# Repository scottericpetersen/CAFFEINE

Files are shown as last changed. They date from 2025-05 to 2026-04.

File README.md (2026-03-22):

# CAFFEINE
**Collaborative Affordable Framework For Experiments In Networked Electronics**

<p align="center">
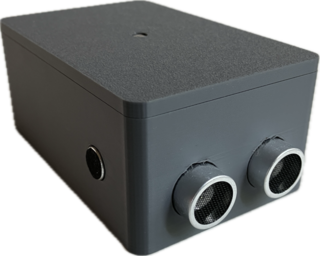
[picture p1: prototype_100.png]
  
</p>

This repository contains files pertaining to the CAFFEINE project, an ongoing research project undertaken by the Open Music Initiative at Yale University. 

## Description

CAFFEINE is a mixed hardware/software framework that enables real-time low-latency sonification of sensor data from wearable embedded systems. The framework utilizes a many-to-many network topology, allowing unlimited pods and clients, constrained only by hardware availability. Wireless, battery-powered pods, built around the ESP32 microcontroller platform, host sensor arrays that capture diverse data, including motion, sound, distance, and light. Data are transmitted to a broker program that routes them to registered clients for sonification or further processing. CAFFEINE prioritizes accessibility and affordability, designed for artists and musicians with minimal technical expertise. Its extensible architecture supports creative applications, from live movement sonification to environmental data-driven compositions, reducing barriers to networked sensor technologies.

## File Directory

Below is a brief description of files found in the CAFFEINE repository

- **client_files**: these are example files showing how to receive and use data from the pods. Currently, there are SuperCollider and Max/MSP examples.
- **osc_programs**: this folder contains the OSC version of the pod and broker programs.
- **paper**: contains the CAFFEINE ICMC 2025 paper and test result files
- **depricated**: contains depricated versions of the CAFFEINE software. We do not recommend using the versions in this file.
- **utilities**: this folder contains the test suite of programs used to procure analysis data of data transmission rates for the CAFFEINE paper.
- **CAD**: contains CAD files for the enclosure

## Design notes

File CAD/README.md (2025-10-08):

## CAFFEINE POD CAD Model

This folder contains OpenSCAD sources for the CAFFEINE enclosure.

Files:
- `box3.scad`: Parametric model for the base and cover
- `box3.stl`: Example export

Prerequisites:
- Install OpenSCAD (`https://openscad.org`)

How to render and export STL:
1. Open `box3.scad` in OpenSCAD.
2. Optional: Adjust parameters at the top of the file (units are millimeters):
   - `box_length`, `box_width`, `box_height`, `wall_thickness`
   - Corner radii: `outer_radius`, `inner_radius`
   - Cover/lip: `cover_thickness`, `lip_height`, `lip_clearance`
   - Holes/vents: `sensor_hole_*`, `sensor_protrusion_*`, `left_hole_*`, `sensor_strip_*`
   - Surface quality: `$fn` (higher = smoother, slower render)
3. Render:
   - Preview: press F5
   - Final (CGAL) render: press F6 (required before exporting STL)
4. Export STL:
   - File → Export → Export as STL
5. For CEID Bambu Printers, no printer settings need to be modified, fill sparcity could be increased for slighly faster print time.

Notes:
- Measurements are in millimeters.
- `lip_clearance` and hole diameters include small tolerances adjusted through trial and error

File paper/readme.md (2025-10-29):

This folder contains the CAFFEINE paper submitted to and included in the procedings of ICMC 2025. The logs folder contains all results of the tests performed for inclusion in the paper. The test code to perform those tests can be found in CAFFEINE/utilities/Test Suite.

ERRATA: 

In the wiring diagram (Fig. 1) the MPU6050 is connected as such: SDA --> pin 5, SCL --> pin 4. However, the current version of the caffeine_osc.ino file as these pins reversed. So either, in the actual circuit, connect SDA to pin 4, and SCL to pin 5. Or, you *should be able to* leave the wiring as in the paper and, in the caffeinepod_osc.ino (and udp version) change the line

```
  Wire.setPins(4, 5);
```

to

```
  Wire.setPins(5, 4);
```

AMBIGUITIES:

The paper does not clarify the nature of the photo-resistor (ldr) and the resistor (R1) connected to it (and GND.) Because photo resistors come in varying resistance values, you should choose the same value for the resistor (R1) as for LDR. This is because the two form a voltage divider where Vout = Vcc(R1/R1+LDR). So at average light, the output values for this system (12-bit ADC) sit around ~2048. As light decreases, resistance of LDR increases and the value goes down to 0. Similarly, as light increases, the value will go up (from ~2048) to a maximum of 4095. You can bias this one way or another by varying the R1 and LDR resistance values. However, it is advisable to do this in software rather than in hardware as you may change the functional range of the light sensor by changing the relationship of R1 and LDR, reducing the range where effective results can be achieved resulting in mostly high (4095) or mostly 0 values when the ambient light level changes.

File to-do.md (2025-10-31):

# Timeline of Improvements to CAFFEINE Framework

Current to-do

- Enclosure battery notches (last on enclosure wishlist)

1. Broker

  - Allow clients to specify multiple pods simultaneously
  - Allow clients to specify which data to receive (ex. only x,y)
  - Allow clients to unregister (stop receiving data)
  - Allow clients to request list of available pods

2. Client
  - graphic visualization of incoming data

3. Pod
  - Software algorithms

DONE: 

- Schedule meeting with CAD/Print team
- Initial Print
- Print V2

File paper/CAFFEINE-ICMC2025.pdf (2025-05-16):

## CAFFEINE: Collaborative Affordable Framework For Experiments in Interactive Networked Electronics

Scott Eric Petersen
Yale University
scott.petersen@yale.edu

Alejandro Mayagoitia
Yale University
alejandro.mayagoitia@yale.edu

ABSTRACT

CAFFEINE is a mixed hardware/software framework that enables real-time low-latency sonification of sensor data from wearable embedded systems. The framework utilizes a many-to-one-to-many network topology, allowing unlimited pods and clients, constrained only by hardware availability. Wireless, battery-powered pods, built around the ESP32 microcontroller platform, host sensor arrays that capture diverse data, including motion, sound, distance, and light. Data are transmitted to a broker program that routes them to registered clients for sonification or further processing. CAFFEINE prioritizes accessibility and affordability, designed for artists and musicians with minimal technical expertise. Its extensible architecture supports creative applications, from live movement sonification to environmental data-driven compositions, reducing barriers to networked sensor technologies. The framework files and utilities can be found on the GitHub project [1].

### 1. INTRODUCTION

Numerous commercial motion capture systems have been developed specifically for use in musical contexts. They have various form factors, but most are designed to be worn[2] or attached to an instrument[3]. Some companies offer a variety of devices[4], but the functionality of each device is fixed and the systems are only extendable in software. In contrast, the CAFFEINE framework integrates open-source software with low-cost, commercially available hardware to provide flexible, extensible configurations that support a wide range of applications.

### 2. DESCRIPTION

CAFFEINE enables real-time, low-latency sonification of sensor input from small, wearable embedded systems called “pods” in a network topology of many-to-one-to-many. Any number of collaborators can register to receive data from any number of pods on the network. The possible number of pods and clients is limited only by hardware. The framework is affordable, reproducible, and accessible for those with little to no hardware and software development knowledge, and the use of the system is simple once it is set

Copyright: ©2025 Scott Eric Petersen et al. This is an open-access article distributed under the terms of the Creative Commons Attribution License 3.0 Unported, (http://creativecommons.org/licenses/by/3.0/) which permits unrestricted use, distribution, and reproduction in any medium, provided the original author and source are credited.

up. Collaborators simply need to power on the pods, start the data broker program, and register their computers with the broker to begin receiving sensor data. The simplicity of the system allows musicians to focus on composition and performance, rather than technology.
We anticipate diverse applications of this system. An obvious use case would be the real-time sonification of movement where a pod is being worn by a dancer. However, a pod or pods could be used to train a machine learning model on complex human gestures. Or, in a conceptual space, we imagine long-scale musical forms could be informed by light and temperature tracked over days or weeks by a pod that is installed and stationary, or being transported through a space by an autonomous vehicle or kinetic sculpture. Whatever the application, the CAFFEINE framework has been designed to lower the barrier to electronic sensors and networked music.

### 3. HARDWARE

### 3.1 Overview

The minimal hardware configuration for CAFFEINE is an embedded system we refer to as a ‘pod’, and a laptop to program the pod and run both the broker program and a client program to sonify the data. An accessible network is also required as communication from the pod to the broker machine is done via Wi-Fi.

### 3.2 Pod

The CAFFEINE pod builds on and advances the embedded system introduced in our previous project, the [project anonymized] [5][6]. It consists of a circuit that connects multiple sensors to an Espressif ESP32 S3 development module [7]. The ESP32 is an ubiquitous microcontroller for embedded applications. Here, we specifically make use of one of its ADC channels and one of its I2C interfaces for sensor input, and its Wi-Fi capabilities for data transmission.

### 3.3 Power

The power for the ESP32 and the sensor array is supplied by a 3.7v 500 mAh lithium ion flat-pack battery [8] and a boost module to step up the voltage from 3.7v to 5v [9]. The boost module has the added benefit of allowing the battery to be charged in situ. The battery run time for this power configuration is approximately 150 minutes. A battery with a larger capacity can easily be substituted for longer performances.

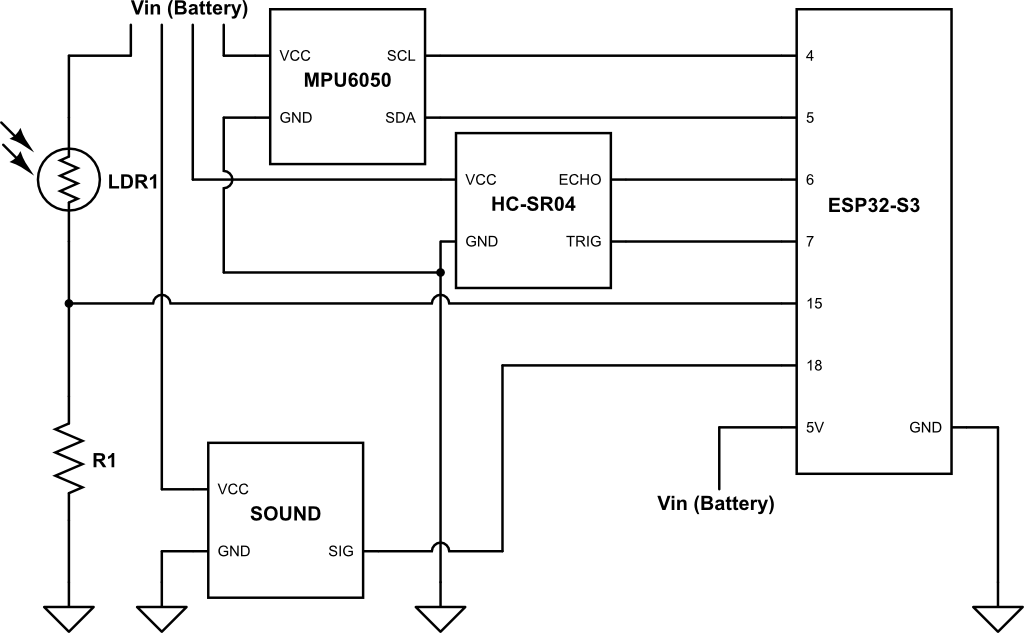
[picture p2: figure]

Figure 1: Circuit diagram for one pod.

### 3.4 Sensor Array

The sensor array consists of an HC-SR04 ultrasonic distance sensor [10], an MPU-6050 accelerometer/gyroscope [11], a Seeed Studio Grove Sound Sensor [12], and a photoresistor. The HC-SR04 distance sensor has an operational range of 2cm to 4m. However, in our tests, the device is unreliable at its extremes and is most stable between 11 cm and distances under 3.5 m. Additionally, noise occurs when the sensor is suddenly moved from the short end of its range to its maximum distance. The proper use of a low-pass filter to avoid noise is important if distances are used as triggers for musical events.
The MPU-6050 has a 3-axis accelerometer, a 3-axis gyroscope sensor, and a temperature sensor. The device is often used in drone construction and anywhere the orientation of a moving object is important [13]. Here, we provide only for the sending of the X, Y, and Z rotational velocity of the pod; however, sending other values is as simple as querying them. There are many libraries available for the MPU-6050 that simplify the acquisition and processing of its various sensor data. For our framework, we chose a library that was as lightweight and specific to the sensor as possible [14].
The sound sensor and the photoresistor are simple devices that return values based on momentary loudness and ambient light levels.

### 3.5 Cost

All pod components are commercially available. The total cost of the components required to build one pod, including a prototyping breadboard and cables, is approximately $50. To be cost-effective, many of the components we use are sold in packs of three to five. Thus, the cost of constructing subsequent pods decreases significantly. To illustrate, the market cost to obtain all the necessary parts for five pods from reputable online retailers is approximately $158 at the time of writing.

### 4. NETWORK TOPOLOGY

The network topology of many-to-many via a data broker means that only one IP address needs to be known for the system to function; the IP address of the computer that runs the broker program. All pods must be individually named and programmed with the IP address of the broker, and all clients must use that address to register for data. Institutional and home networks are compatible with CAF-FEINE; however, we recommend using a dedicated, private router that is offline and configured with a static IP address for the computer running the broker program. This setup eliminates the need to reprogram the pods when changing locations and only requires the broker’s IP address to be published once, simplifying client registration regardless of where the system is deployed.

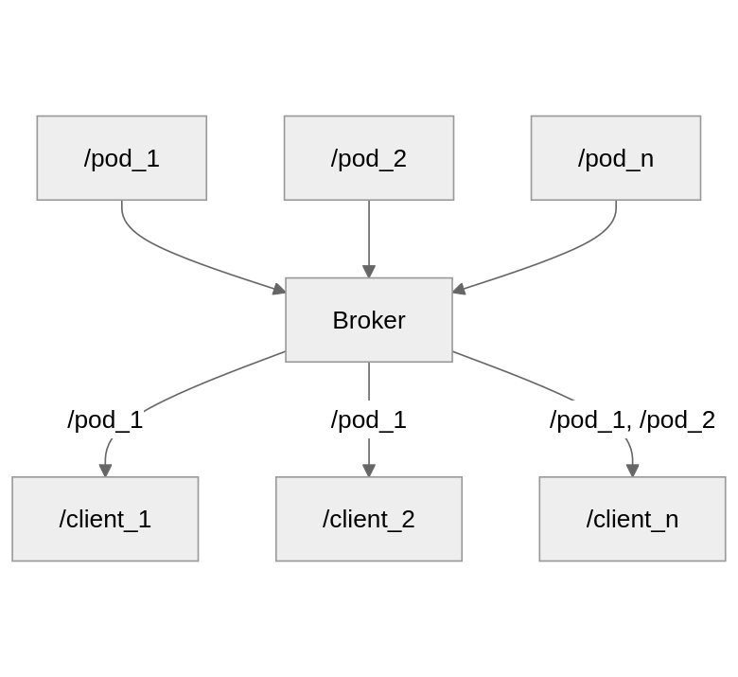
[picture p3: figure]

Figure 2: A CAFFEINE configuration where n number of pods are connected in an arbitrary way to n number of clients via the broker.

### 5. SOFTWARE

### 5.1 Overview

The software configuration for CAFFEINE consists of two files, an Arduino file that runs on the pod that defines its behavior, and a Python file that runs on the computer acting as the data broker that receives messages from the pod and forwards them to any registered clients on the localhost or the network. The last piece of a complete system is the client software to sonify the data received from the broker. Although that software must be written by the user of the system according to their specific needs, we provide SuperCollider examples that demonstrate functionality and best practices.

### 5.2 Embedded System Program

The pod program defines the name of the pod that identifies it to the broker. It registers the target computer running the broker software, attaches the pod to a specified network, measures the values from the attached sensor array, and sends those data to the broker program at a userspecified interval via one of two methods, either as a string via UDP or as typed data via OSC. Messages sent as strings via UDP are sent with the name of the pod followed by space-delimited sensor data as a string. Packets sent as OSC messages prepend the pod name as a symbol /pod1 and then an array of data where each comma denotes a potentially different data type. An example message sent via OSC might be

/ pod1 : [ 0 . 0 3 0 , 0 . 0 1 0 , −0.863 , 2253 ,
2 2 . 0 9 , 97]

where the first three data points are the X, Y, and Z values of the MPU-6050, the fourth data point is the loudness, the fifth is the distance registered by the HC-SR04 in centimeters, and the last is the light value registered by the photoresistor.

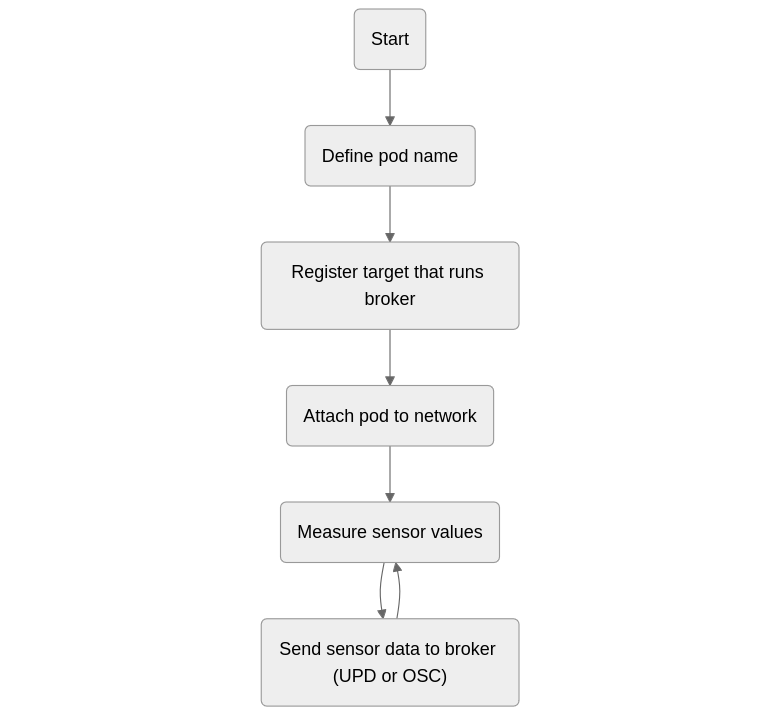
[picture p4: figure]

Figure 3: Embedded System Program flow control.

UDP and OSC communication have pros and cons. For UDP, string concatenation is done via a fixed-size character array. Thus, the memory allocation is secure and consistent, and messages are sent and received regularly, with jitter and packet loss typical of any UDP communication. However, this method requires that the messages are parsed once they arrive at the client, as, for example, in SuperCollider, data are received as symbols. The user must convert those symbols to an appropriate data type to be used in sonification, for example, to an integer to be used for frequency control. Languages like SuperCollider and PureData easily accommodate this requirement, but other programs such as digital audio workstations may not. OSC allows client programs to receive data in the type they were sent and has the added benefit of being universally supported by audio software. This results in data that are usable without conversion. However, the size of the data (e.g. individual sensor readings) in the OSC message must be managed to maintain consistent message size. Our OSC program rounds all values to the second decimal point, which may or may not be best for all use cases, but results in consistent message size. Users must also carefully consider what OSC library they use. Our testing showed that several available libraries resulted in communications that suffered from occasional periods of increased latency. The library used in CAFFEINE and the one that we recommend is ArduinoOSCWiFi.
In either case, the user should choose the method that makes the most sense for their project requirements. If an exact message size is not required, OSC should be preferred for ease of use and maximal compatibility with audio software.

### 5.3 Data Broker Program

The broker program defines how the data from the pods are received, registers clients who want to receive data and the specific pods from which they want it, and forwards the data as it is sent.
The broker is configured to accept data from any IP address on the network as long as the message being sent is prefixed with the name of a pod registered by the broker. It defines a port to receive data (5001) and a port to send data to clients (9001).
Clients register with the broker by sending a /register message with the name of the target pod as the second argument. The broker records the IP address for the client and associates it with the specified pod, for example, /pod1. When messages are received from /pod1, the broker checks a dictionary for registered clients to receive data from that pod and forwards the data to the appropriate clients. Clients may register to receive data from any and all pods on the network.
As with the pod program, there are two versions of the broker, one that parses strings and one that receives and forwards OSC messages [15].

### 5.4 Sonification Program

We do not specify a program, but rather a set of considerations that electronic music practitioners will be familiar with when working with abstract, non-musical data. The data from the pod are in arbitrary ranges determined by the sensors themselves. Value ranges may be unipolar or bipolar, and may be small or large. In addition, the data are received at a clocked rate determined by the user, but the exact timing cannot be counted on due to network jitter. The end user of the system must determine how many pods they want to receive data from, what sensors from each array they will use, how often they want to use those values in their program, and how to map the values to musical parameters in their chosen system.

### 6. DATA TRANSMISSION TESTING

Preliminary observations of the CAFFEINE pod indicate a high degree of responsiveness during sonification, particularly when standard noise mitigation strategies such as low-pass filtering are employed. To precisely measure communication parameters, namely latency, packet loss, and transmission rate, modifications were made to the OSC version of both the pod and broker programs. Furthermore, a supplementary utility, endpoint logger.py, was developed to support end-to-end latency measurement.

### 6.1 Software Modifications for Testing

To facilitate precise latency measurements, the pod firmware was augmented to synchronize with NTP and include both a timestamp and a sequential message counter in each OSC message. Corresponding modifications were implemented in the broker program to compute pod-to-broker latency by comparing the received timestamp against its own system time. Packet loss was inferred by detecting discontinuities in the message count sequence. The broker was also updated to record latency values in a CSV file and to forward complete messages—including timestamp—to one or more client machines running the logger program, which computed end-to-end latency by comparing the pod’s original timestamp with the current time on the client.

### 6.2 Hardware Configurations

Three pod configurations were designed to simulate different use cases:

- Pod 1 (full configuration): Included MPU-6050 gyroscope, distance sensor, light sensor, and sound sensor.
- Pod 2: Included only the MPU-6050 gyroscope.
- Pod 3: Included only the light and sound sensors.

### 6.3 Testing Methodology

Two sets of experiments were conducted:

1. Single-Pod Tests: Each configuration was individually evaluated using a set-up consisting of one pod, one computer running the broker, and one client computer running the endpoint logger. This configuration simulated a typical performance scenario involving a single performer and a single data sonifier.
2. Multi-Pod Tests: The three pod configurations were evaluated concurrently using one broker computer and three client machines, each assigned to receive data from a distinct pod. This configuration was designed to model a multi-pod performance scenario.

For all tests, a dedicated private network was used. The test devices were approximately 20 feet away from the router with a partial line of sight.

### 6.4 Results

A pronounced initial spike in latency and packet loss was observed during the startup phase as each pod connected to the network. This behavior is illustrated in Figure 4, which shows the first 500 samples from Pod 1.

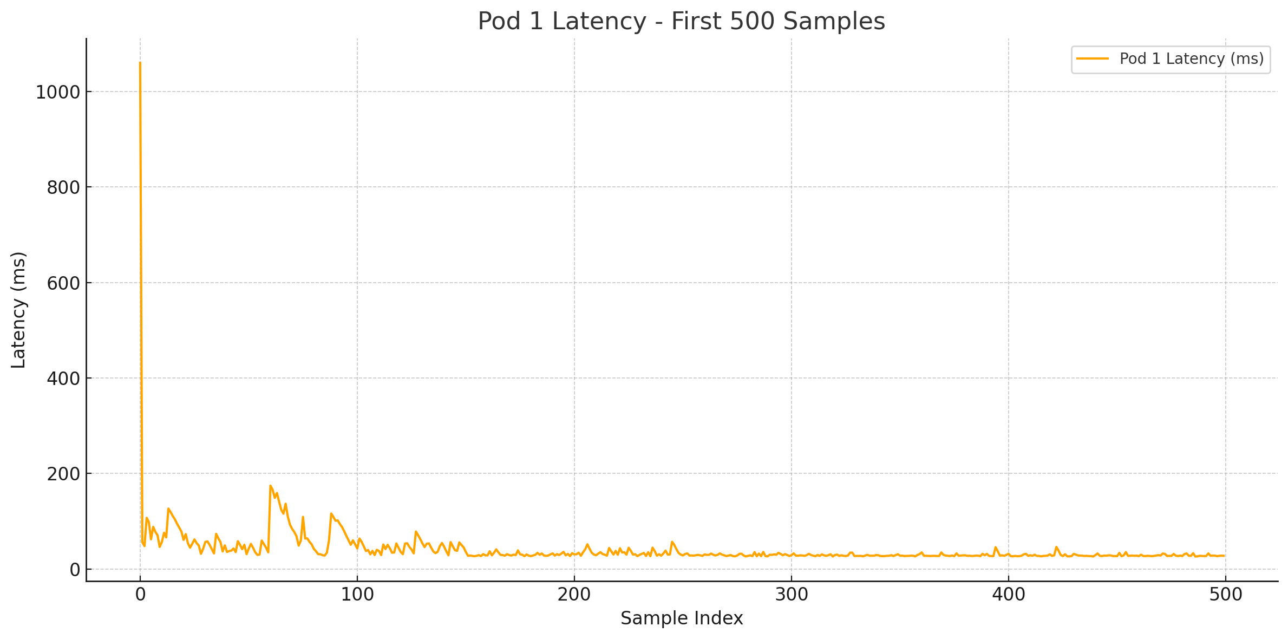
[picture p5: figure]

Figure 4: Latency plot of the first 500 samples received from Pod 1 in the single-pod tests.

A recurrent pattern of packet loss was detected in all configurations: Three packets were received, followed by a brief loss interval, after which the transmission stabilized for the remainder of the session (see Table 1).
Although Pods 2 and 3 exhibited similar startup behavior, the magnitude of latency and packet loss was reduced relative to Pod 1, as shown in Figure 5.

Table 1: Packet loss for Pod 1 over the first seven samples.

Latency | Seq number | Dropped | Total
1484.593 | 0 | 0 | 0
480.142 | 1 | 0 | 0
470.851 | 2 | 0 | 0
81.064 | 41 | 38 | 38
71.51 | 42 | 0 | 38
62.811 | 43 | 0 | 38
55.271 | 44 | 0 | 38

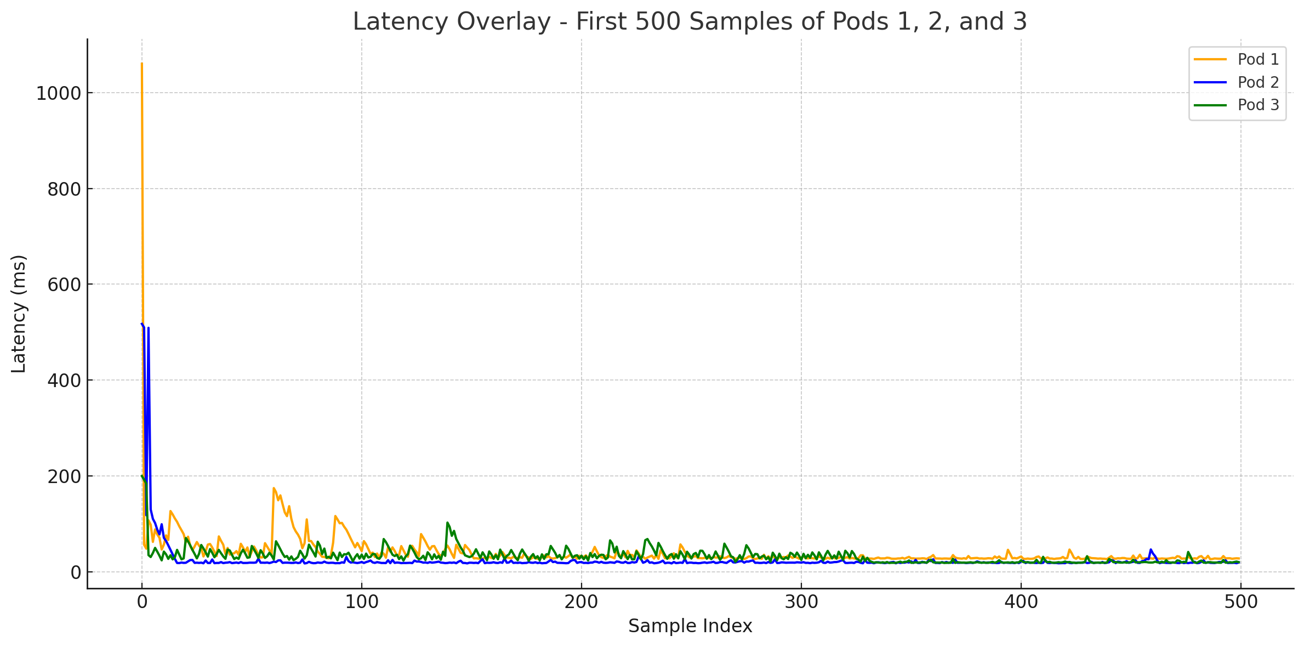
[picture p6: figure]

Figure 5: Latency plot of the first 500 samples received from Pods 1, 2, and 3 in the single-pod tests.

Excluding the initial samples, a comparative latency analysis revealed that Pod 1, with the complete hardware configuration, consistently demonstrated a higher average latency (7-9 ms) than the other two configurations, in both individual and simultaneous tests (see Figure 6.)

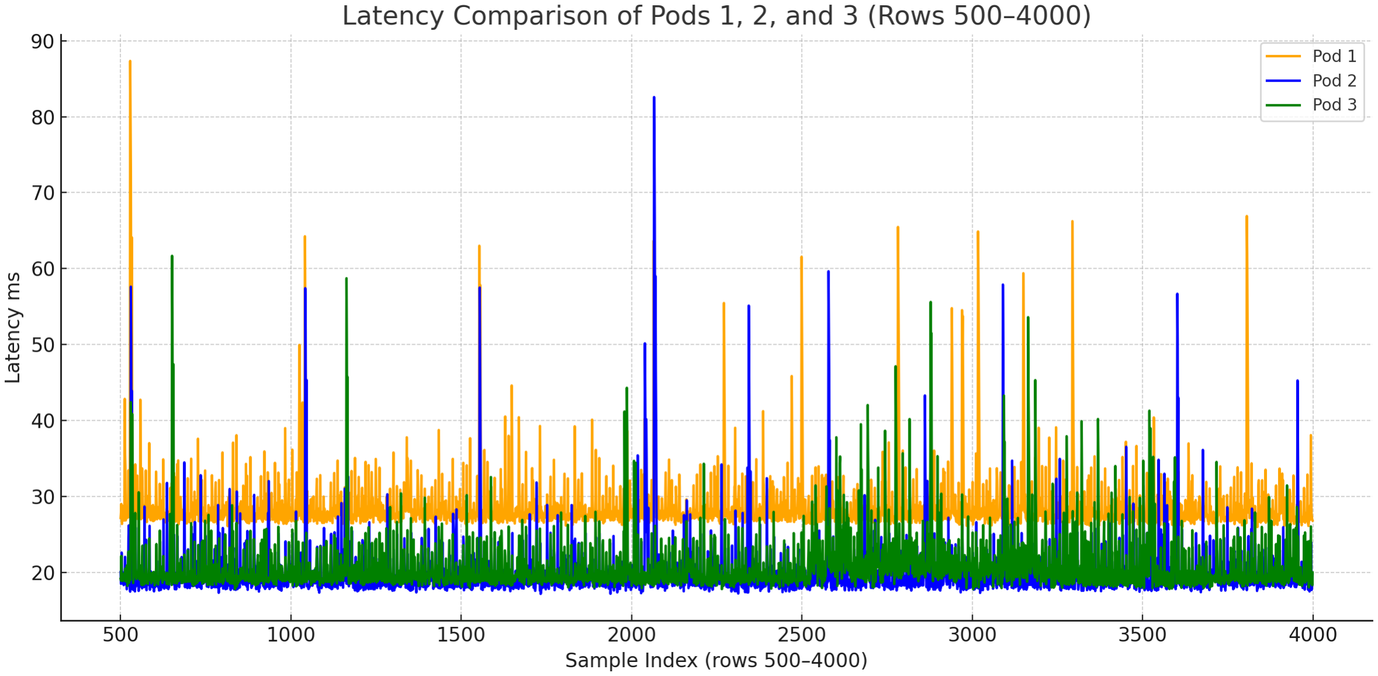
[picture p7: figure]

Figure 6: Overlay plot showing latency for Pods 1, 2, and 3 from the single-pod tests.

The average message throughput for both sets of tests was measured at approximately 98 messages per second (see Table 2), with rates slightly faster for the multi-pod arrangement. Both sets of tests show a somewhat broad minimum to maximum latency range, although the mean latency remained within acceptable limits for real-time performance scenarios (see Tables 3 and 4).

### 6.5 Interpretation of Testing Data

Somewhat counterintuitively, the tests show that overall performance did not degrade in the multi-pod tests (see Table 4), and in some instances are actually better, suggesting that the framework’s many-to-one-to-many communication model scales effectively under load (Figure 7). It should also be noted that the inclusion of diagnostic and logging routines introduced additional computational overhead. In live contexts, actual performance may improve

Table 2: Message throughput for all pods in both single and multi-pod tests. Numbers are messages per second.

Pod | Avg Messages
| Pod 1 (ind) | 96.78
| Pod 2 (ind) | 98.17
| Pod 3 (ind) | 98.33
| Pod 1 (grp) | 99.14
| Pod 2 (grp) | 99.33
| Pod 3 (grp) | 98.29

Table 3: Latency Statistics for single-pod tests (Rows 500– 4000) where all times are in milliseconds

Pod | Min Latency | Max Latency | Avg Latency
Pod 1 | 26 | 87.33 | 28.63
Pod 2 | 17.21 | 82.58 | 19.95
Pod 3 | 17.82 | 61.69 | 20.7

modestly in the absence of such instrumentation.
Initial tests were performed on an enterprise network where significantly poorer results were obtained. The presence of an unknown number of additional network devices and the lack of proximity to the wireless access point (WAP) resulted in higher latency and packet loss, causing us to abandon the tests. For optimal performance, users are strongly advised to use a dedicated router.

### 7. WORKFLOW

Users of the CAFFEINE framework must purchase the components and assemble the circuit described here to complete their pod. Because the ESP32 has many additional pins unused in our configuration, the pod can be easily extended with additional sensors. Alternately, given fewer sensors, inputs may be omitted. In either case, only small changes to the pod program are necessary.
The Arduino development software and Python 3 must also be installed if they are not already on the development system. The pods must initially be programmed by the Arduino IDE. The broker software must be run on either the same or a different computer whose IP address is known and entered into both the pod program and the client program. Finally, using an audio program such as SuperCollider, the user can register with the broker to begin receiving real-time sensor data from the pod.

### 8. FUTURE DIRECTIONS

### 8.1 Enclosures

CAFFEINE describes a system and configuration, but does not specify the end-use of the system; therefore, no enclosures have been described. Because applications will vary considerably, housings for the pod will take diverse forms. For example, if a live coder wants to incorporate the dancing of members of their audience into their performance, the enclosure for the pod should be as comfortable and as streamlined as possible. In some cases, for example, to track the movements of hikers as they traverse some re-

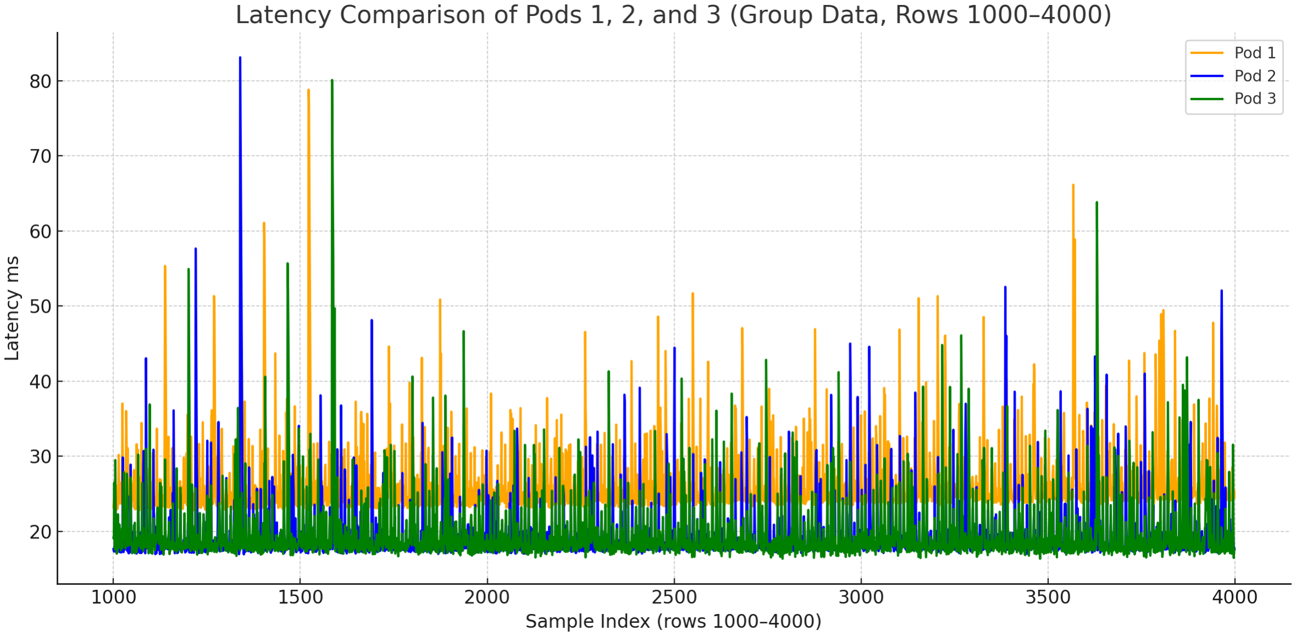
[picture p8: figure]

Figure 7: Overlay plot showing latency for Pods 1, 2, and 3 from the multi-pod test.

Table 4: Latency Statistics for the multi-pod test (Rows 1000–4000) where all times are in milliseconds.

Pod | Min Latency | Max Latency | Avg Latency
Pod 1 | 22.79 | 78.79 | 26.12
Pod 2 | 16.91 | 83.09 | 19.47
Pod 3 | 16.33 | 80.08 | 19.69

mote location, it would be better to prioritize ruggedness. Such an application could see the system augmented with a photovoltaic cell when electricity is unavailable.

### 8.2 Data processing, Profiles, and Classes

The data returned from the pod are not processed. While this may be preferable to advanced users, others might prefer pre-processed data that can be readily and intuitively applied in a musical context. For convenience, processing could be linked to a specific profile that also determines which sensor data are received. For example, a profile named /gyro might exclusively return data from the MPU-6050 sensor, with an n-dimensional Kalman filter applied to stabilize the X, Y, and Z values. These stabilized values could then be assigned to commonly used musical ranges, for example, -1 to 1 for panning, 0 to 1 for amplitude, and 100 to 5000 for filter cut-offs or other frequencyrelated parameters. To streamline these processes, a program class or object could be developed for popular audio programming languages, simplifying integration and use.

### 8.3 Alternate Network Topologies

It may be the case that with small numbers of pods and clients, a peer-to-peer network topology may be better. Without an intermediary broker, communication should be faster. A list of the static IP addresses of the individual pods running servers could be distributed to users, and the data sent directly to their connected clients. If the P2P topology actually resulted in lower latency, testing would be required to determine at what scale, if any, that configuration failed to improve communication rates.

### 9. PARTS LIST

1. Espressif ESP32 S3 Dev Module [7]
2. HC-SR04 Ultrasonic Distance Sensor [10]
3. MPU-6050 module [11]

4. Seeed Studio Grove Sound module [12]
5. Photoresistor - resistance values vary and should be chosen based on overall light levels in the anticipated performance space. For lower light levels, prefer lower resistance values.
6. 10k Ohm resistor
7. 3.7V Lipo Battery 500mAh Rechargeable Lithium ion Polymer Battery 502535 Lithium Polymer ion Battery with JST Connector [8]
8. Seeed Studio Lipo Rider Plus (Charger/Booster) -5V/2.4A USB Type C [9]
9. micro USB cable
10. WB-102 Solderless Breadboard
11. 20 solderless breadboard cables

References

[1] CAFFEINE, Yale Open Music Initiative. [Online]. Available: https://github.com/scottericpetersen/CAFFEINE (https://github.com/scottericpetersen/CAFFEINE)
[2] MiMU Gloves, MI.MU GLOVES LIMITED. [Online]. Available: https://mimugloves.com/about/
[3] MUGIC® Motion Sensor 2.0, MUGIC MOTION. [Online]. Available: https://www.mugicmotion.com/
[4] Instruments of Things Product Page, Instruments of Things GmbH. [Online]. Available: https: //instrumentsofthings.com/collections/frontpage
[5] S. Petersen, M. Santolucito, and K. Kaczmarek, “Studio Report: Yale Open Music Initiative,” in Proceedings of the 2019 International Computer Music Conference, 2019, pp. 530–532.
[6] OMI-Pod, Yale Open Music Initiative. [Online]. Available: https://github.com/Yale-OMI/OMI-Pod
[7] ESP32-S3-DevKitC-1, | Espressif | Sys-
tem | Co. | [Online]. | Available: | https:
//docs.espressif.com/projects/esp-dev-kits/en/ latest/esp32s3/esp32-s3-devkitc-1/index.html (https://docs.espressif.com/projects/esp-dev-kits/en/latest/esp32s3/esp32-s3-devkitc-1/index.html)
[8] Li-Polymer | Battery | Technology | Specification,
Shenzhen PKCELL Battery Co. [Online]. Available: https://cdn-shop.adafruit.com/product-files/1578/C1854+PKCell+Datasheet+Li-Polymer+503035+ 500mAh+3.7V+with+PCM.pdf (https://cdn-shop.adafruit.com/product-files/1578/C1854+PKCell+Datasheet+Li-Polymer+503035+500mAh+3.7V+with+PCM.pdf)
[9] Lipo Rider Plus(Charger/Booster) - 5V/2.4A,
Seeed | Technology | Co. | [Online]. | Avail-
able: | https://mm.digikey.com/Volume0/opasdata/
d220001/medias/docus/338/106990290 Web.pdf (https://mm.digikey.com/Volume0/opasdata/d220001/medias/docus/338/106990290_Web.pdf)
[10] Ultrasonic Ranging Module HC-SR04, Elecfreaks, Inc. [Online]. Available: https://cdn.sparkfun.com/datasheets/Sensors/Proximity/HCSR04.pdf (https://cdn.sparkfun.com/datasheets/Sensors/Proximity/HCSR04.pdf)
[11] MPU-6000 and MPU-6050 Product Specification, InvenSense Inc., August 2013. [Online]. Available: https://invensense.tdk.com/wp-content/uploads/2015/02/MPU-6000-Datasheet1.pdf (https://invensense.tdk.com/wp-content/uploads/2015/02/MPU-6000-Datasheet1.pdf)
[12] Grove - Sound Sensor User Manual, Seeed Technology Co., September 2015. [Online]. Available: https://www.mouser.com/catalog/specsheets/ Seeed 101020023.pdf (https://www.mouser.com/catalog/specsheets/Seeed_101020023.pdf)
[13] S. Sing Kang, N. T. Singh, and R. Grover, “Improving Drone Agility and Stability with Advanced Flight Control Systems Using MPU-6050 IMU and High-Fidelity Simulation,” in 2024 International Conference on Cybernation and Computation (CYBER-COM), 2024, pp. 121–127.
[14] R. J. Fetick and tockn, “MPU6050 light,” accessed January 12, 2025. [Online]. Available: https://github.com/rfetick/MPU6050 light?tab=readme-ov-file (https://github.com/rfetick/MPU6050_light?tab=readme-ov-file)
[15] H. Tai, F. Bruggisser, and S. Goodchild, “ArduinoOSC,” accessed January 13, 2025. [On-
line]. | Available: | https://github.com/hideakitai/
ArduinoOSC/tree/main (https://github.com/hideakitai/ArduinoOSC/tree/main)

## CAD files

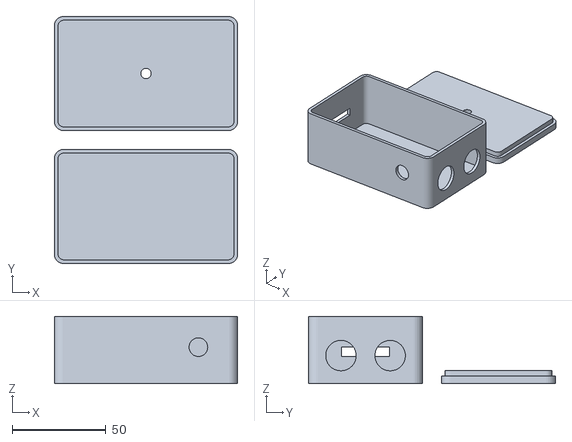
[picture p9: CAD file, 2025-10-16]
CAD/box4.stl
98.0 x 131.9 x 36.0

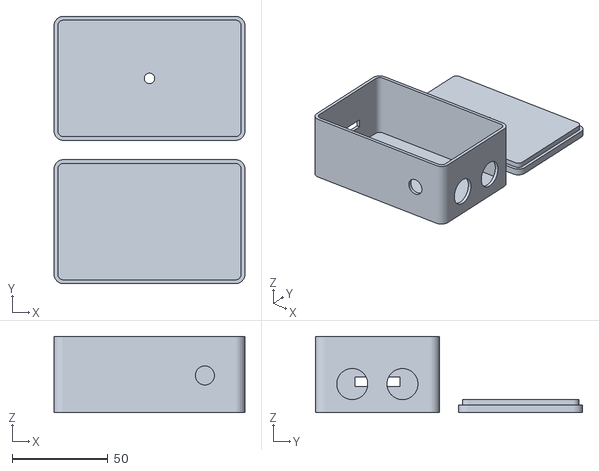
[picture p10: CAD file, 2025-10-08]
CAD/box3.stl
100.0 x 139.9 x 40.0

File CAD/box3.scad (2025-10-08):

$fn = 30;

box_length = 100;    // 10 cm
box_width = 65;      // 6.5 cm
box_height = 40;     // 5 cm
wall_thickness = 2;  // 0.2 cm

// Corner rounding
outer_radius = 5;
inner_radius = 3;

// Cover parameters
cover_thickness = 4;
lip_height = 3;
lip_clearance = 0.2;

sensor_hole_diameter = 16 + 0.3;
sensor_hole_radius = sensor_hole_diameter / 2;
edge_to_edge_gap = 10;  
sensor_hole_spacing = sensor_hole_diameter + edge_to_edge_gap; 
sensor_hole_height = 15; 

// Cover hole parameters
sensor_protrusion_diameter = 5.5; // 5.5mm hole for 4.2×3.5mm rounded rectangle
sensor_protrusion_radius = sensor_protrusion_diameter/2;

// Back strip parameters
sensor_strip_z = 15 - 1.5;       
sensor_strip_height = 5;         
sensor_strip_length = 23.5; 

/* Sound sensor hole */
left_hole_diameter = 9.7 + 0.3;                  
left_hole_radius = left_hole_diameter/2;
left_hole_x = box_length - 21;              // Center horizontally
left_hole_z = box_height - 30 + 9.5;              // Center vertically

module rounded_rect(x, y, z, r) {
    hull() {
        translate([r, r, 0]) cylinder(r=r, h=z);
        translate([x - r, r, 0]) cylinder(r=r, h=z);
        translate([r, y - r, 0]) cylinder(r=r, h=z);
        translate([x - r, y - r, 0]) cylinder(r=r, h=z);
    }
}

module base() {
    difference() {
        // Outer shell
        rounded_rect(box_length, box_width, box_height, outer_radius);
        
        // Inner cavity
        translate([wall_thickness, wall_thickness, wall_thickness]) 
        rounded_rect(
            box_length - 2*wall_thickness, 
            box_width - 2*wall_thickness, 
            box_height - wall_thickness + 0.1,
            inner_radius
        );
        
        // Top recess
        translate([2*wall_thickness, 2*wall_thickness, box_height - lip_height]) 
        rounded_rect(
            box_length - 4*wall_thickness, 
            box_width - 4*wall_thickness, 
            lip_height + 0.1,
            inner_radius - 1
        );
        
        // Front sensor holes
        translate([box_length, (box_width/2) - (sensor_hole_spacing/2), sensor_hole_height])
        rotate([0, -90, 0])
        cylinder(r=sensor_hole_radius, h=wall_thickness + 0.02);
        
        translate([box_length, (box_width/2) + (sensor_hole_spacing/2), sensor_hole_height])
        rotate([0, -90, 0])
        cylinder(r=sensor_hole_radius, h=wall_thickness + 0.02);
        
        // Back face ventilation strip
        translate([-0.01, (box_width - sensor_strip_length)/2, sensor_strip_z])
        cube([wall_thickness + 0.02, sensor_strip_length, sensor_strip_height]);
        
        translate([left_hole_x, 0.01, left_hole_z])
        rotate([-90, 0, 0])
        cylinder(r=left_hole_radius, h=wall_thickness + 0.02);
    }
}

module cover() {
    difference() {
        union() {
            rounded_rect(box_length, box_width, cover_thickness, outer_radius);
            
            translate([wall_thickness, wall_thickness, -lip_height]) 
            rounded_rect(
                box_length - 2*wall_thickness,
                box_width - 2*wall_thickness,   
                lip_height + 0.2,              
                inner_radius     
            );
        }
        
        translate([
            box_length/2,
            box_width/2,
            -lip_height - 0.01
        ])
        cylinder(
            d = sensor_protrusion_diameter,
            h = cover_thickness + lip_height + 0.1
        );
    }
}

// Visualization
base();
translate([box_length, box_width + 10, cover_thickness]) 
rotate([0, 180, 0]) 
cover();

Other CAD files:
CAD/box4.scad

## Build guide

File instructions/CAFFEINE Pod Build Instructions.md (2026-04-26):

# CAFFEINE Pod Build Instructions

## Overview

This document will show how to put together a CAFFEINE pod. These are the parts needed:

- ESP32S3
- Breadboard
- 3D Printed Enclosure
- MPU6050 Gyroscope/Accelerometer
- Sound Sensor
- Photoresistor
- HC-SR04 Distance Sensor
- LiPo Rider Plus
- Battery
- Resistor (how many ohms?)
- Jumper wires (15 male-to-male, 6 female-to-male?)

## Build Instructions

### Step 0: Getting the components ready to build

Before wiring anything up, we need to make sure all the components are ready. When buying parts online, they may come with no sockets soldered on or not completely assembled. Make sure the following components all have sockets soldered on:

- MPU6050 (if you want, you can just solder the VCC, GND, SCL, AND SDA pins)
- Sound Sensor
- Distance Sensor

Next, we need to modify the components a little to correctly fit everything in the CAFFEINE pod. Modify the components as shown below:

**MPU6050**

We just need the VCC, GND, SCL, and SDA pins, so if your MPU6050 has more pins soldered on, you'll have to clip them off. This is easy to do using an angle cutter or wire clippers. Your MPU6050 should look like this:

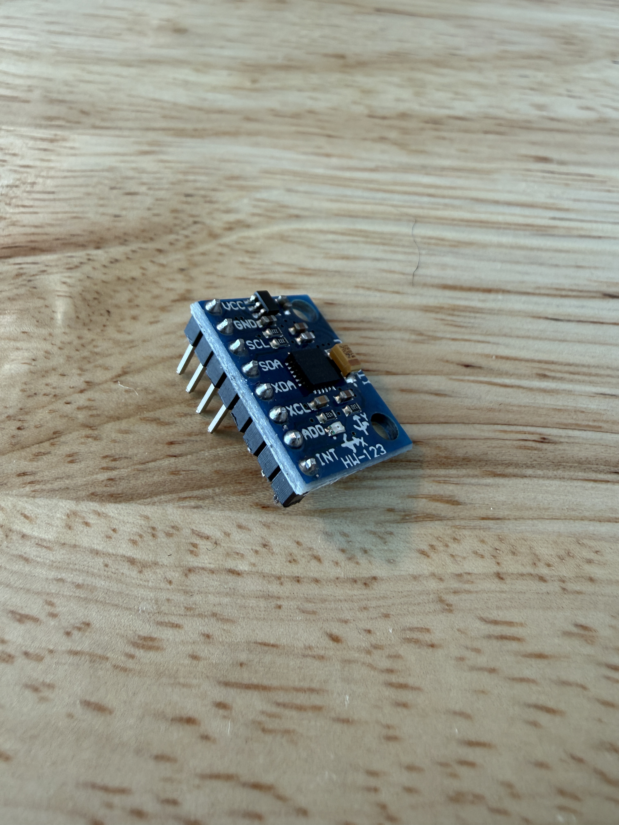
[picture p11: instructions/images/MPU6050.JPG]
MPU6050


**Sound Sensor**

Make sure the male headers stick out at a 90 degree angle from the circuit board. If they do not, you may have to bend them into shape, which can be done using some pliers. the sound sensor should look like this:

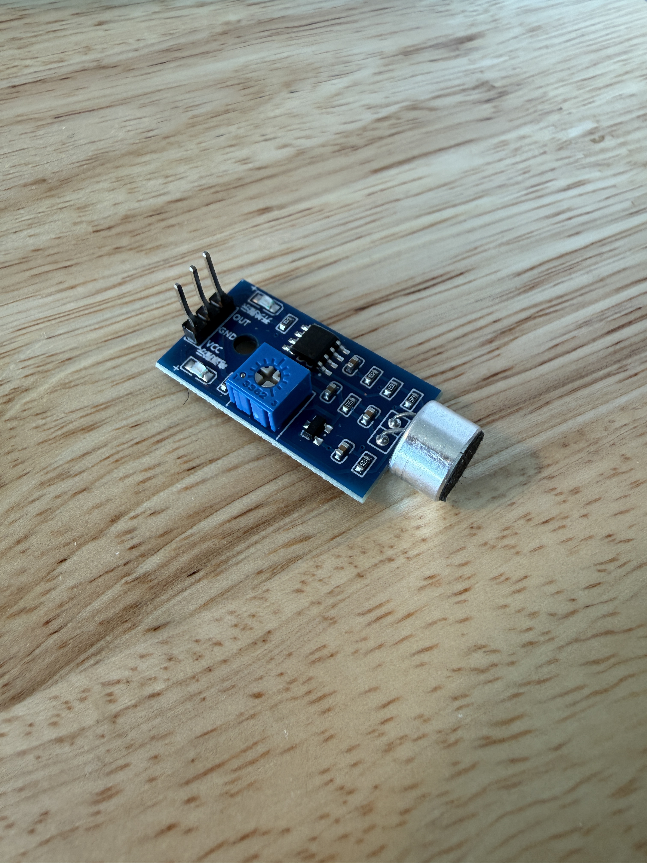
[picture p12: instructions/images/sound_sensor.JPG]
sound_sensor


**Distance Sensor**

Like the sound sensor, we need to make sure the male headers on the distance sensor stick out at a 90 degree angle from the circuit board. The distance sensor should look like this:

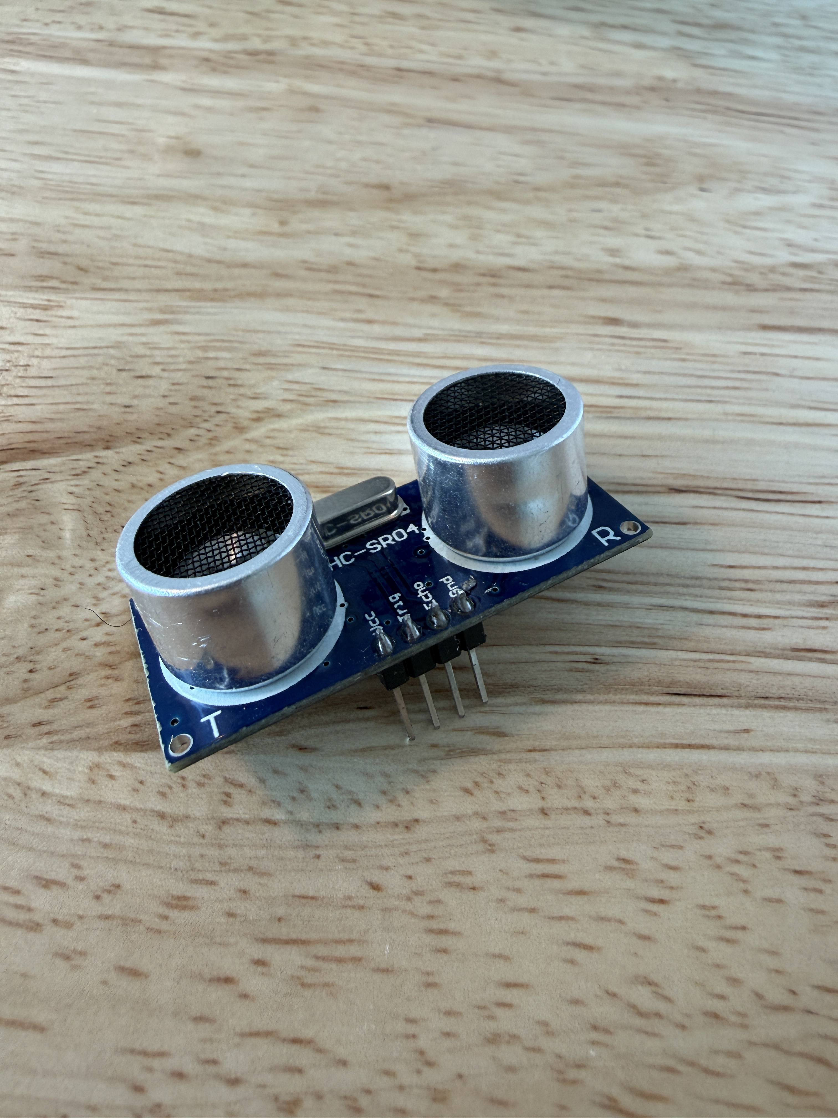
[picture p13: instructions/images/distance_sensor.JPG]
distance_sensor


**LiPo Rider Plus**

You will need to solder female headers to the through holes in the LiPo rider plus. When done, it should look like this:
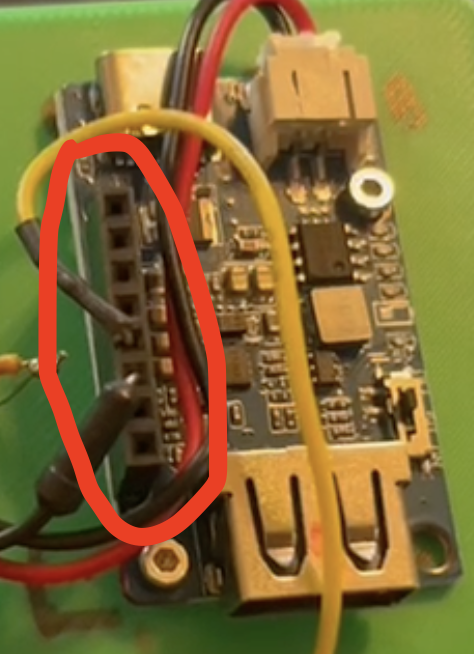
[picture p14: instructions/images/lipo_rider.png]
LiPo rider


Now, we can start putting things together.

### Step 1: Place the distance sensor in the enclosure

You need to poke the distance sensor through the holes in the enclosure. Make sure to place the sound sensor so that the male headers are closer to the open top of the enclosure. After completing this step, the pod should look like this:

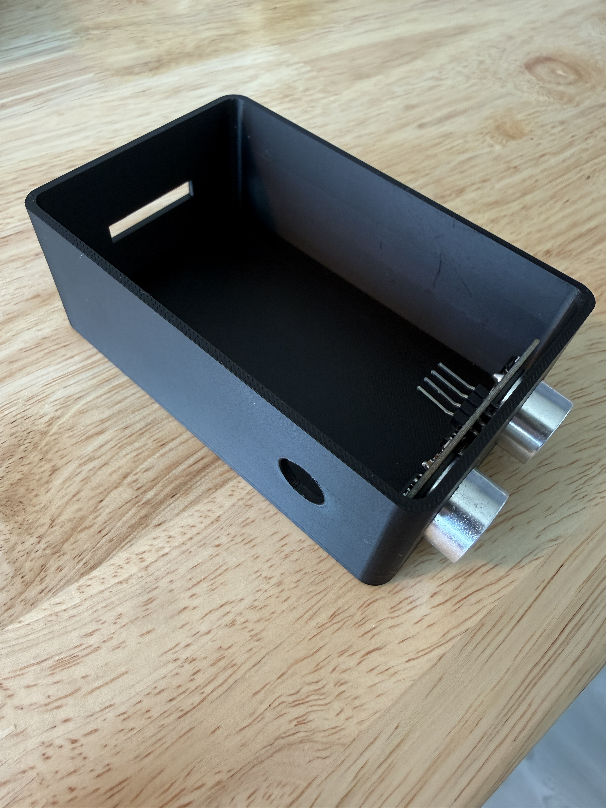
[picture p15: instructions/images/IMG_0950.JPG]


### Step 2: Place the ESP32S3 and the MPU6050 on the breadboard

Place the MPU6050 and the ESP32S3 on the breadboard as shown below:

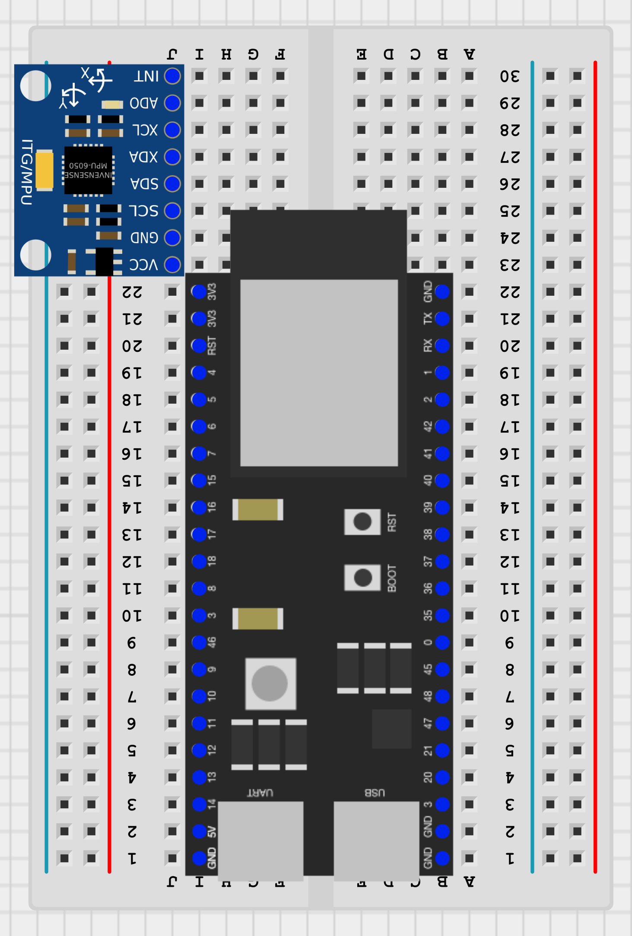
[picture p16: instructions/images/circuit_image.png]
Circuit Image 1


### Step 3: Place the breadboard inside the enclosure

Place the breadboard (which should now have the MPU6050 and the ESP32 connected to it) in the enclosure. You'll need to slide the breadboard under the pins of the distance sensor, as those pins should be sticking out. This is how the pod should look like once this step is complete:

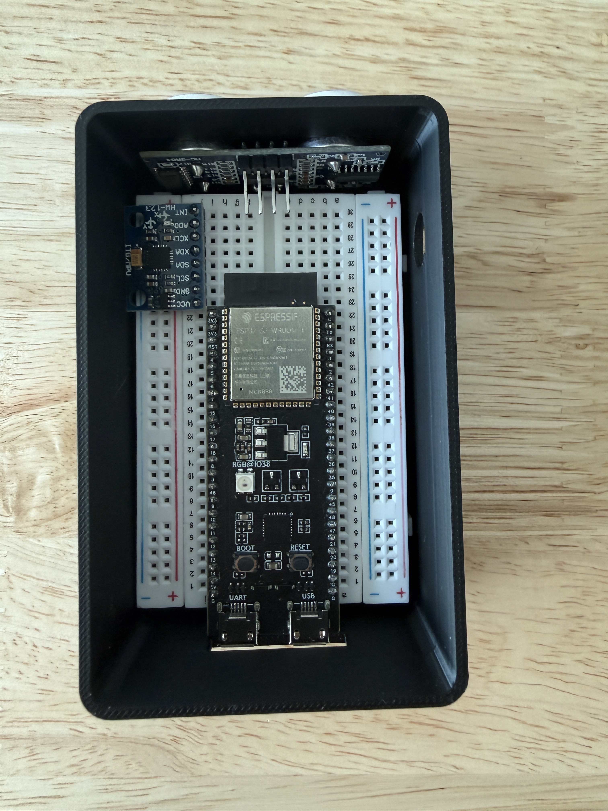
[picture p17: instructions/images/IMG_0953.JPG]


### Step 4: Plug sound sensor into breadboard

Place the sound sensor on the breadboard, leaving some space between the MPU6050 and the sound sensor, as shown in the diagram below:

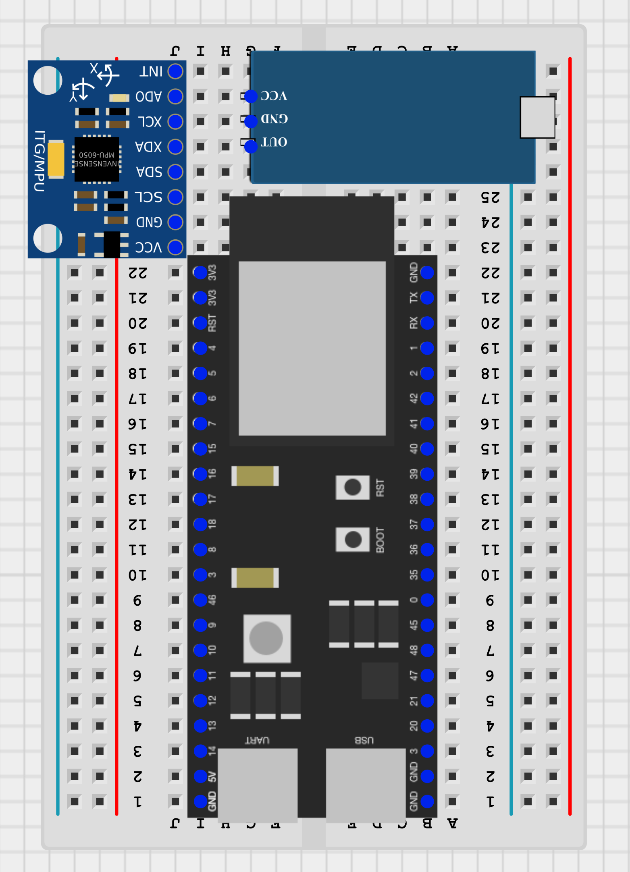
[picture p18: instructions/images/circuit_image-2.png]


(As you can see, the OUT pin on the sound sensor is on the same row as the XDA pin on the MPU6050, the GND pin is on the same row as the XCL pin, and the VCC pin is on the same row as the ADD pin.)

The round end of the sound sensor should stick into the hole on the side of the enclosure. It can be a little tricky to make it all fit together. It is recommended to hold the round end in place while placing the pins into the breadboard.

Here is how the pod should look after this step is completed:
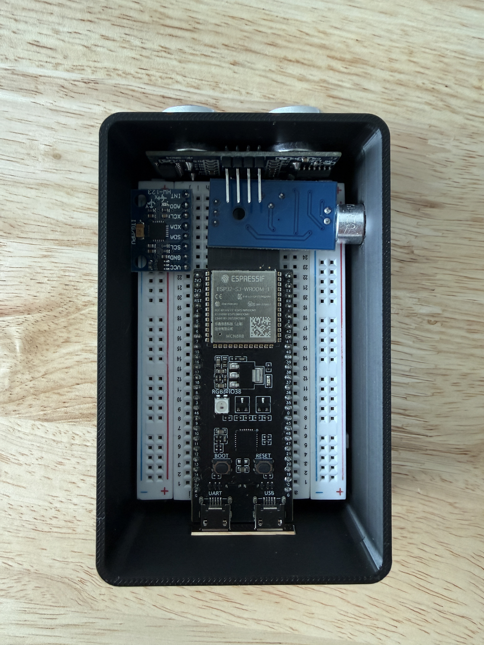
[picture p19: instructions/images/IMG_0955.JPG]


### Step 5: Wire the sensors to the ESP32

**First, make sure the power rails are connected**

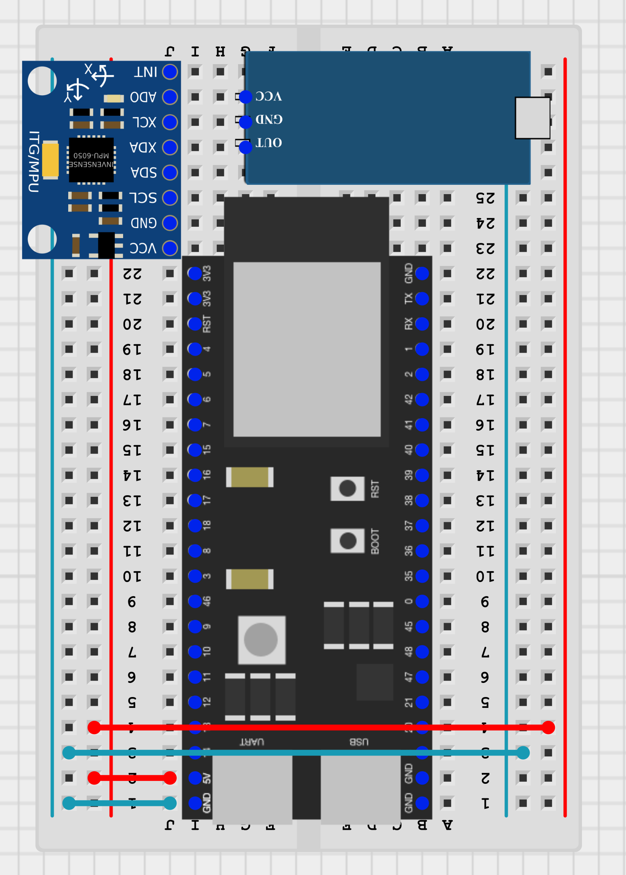
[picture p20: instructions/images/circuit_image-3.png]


**Second, wire the VCC, GND, SCL, and SDA pins on the MPU6050**

SDA should connect to pin 5 on the ESP32, and SCL should connect to pin 4:

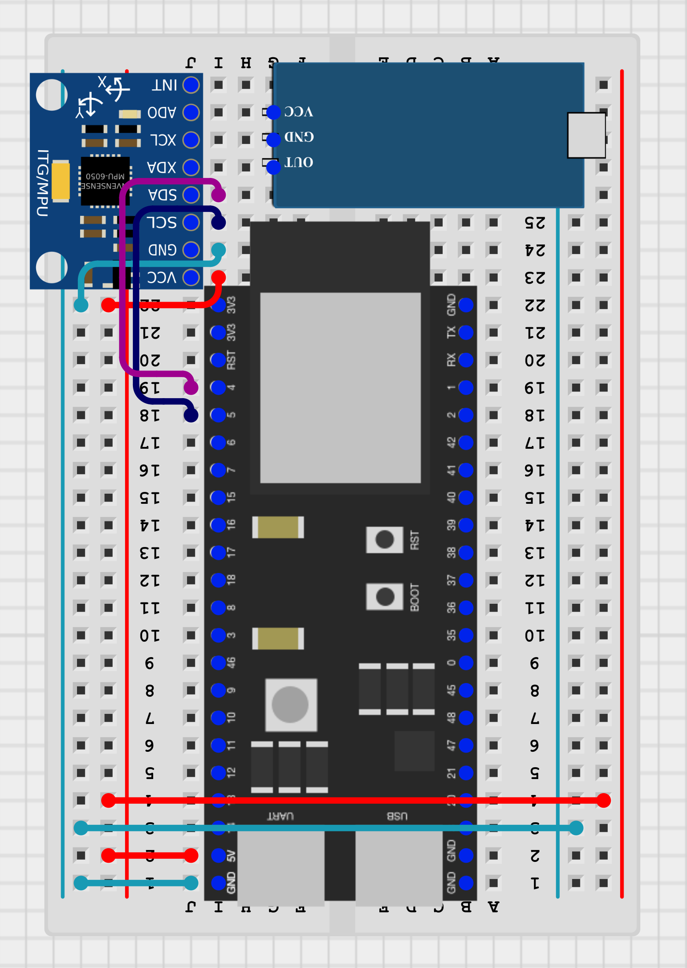
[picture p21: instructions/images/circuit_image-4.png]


**Next, connect the sound sensor**

Connect the VCC pin on the sound sensor to the power rail, connect the GND pin to the ground rail, and connect the OUT pin to the ESP32:

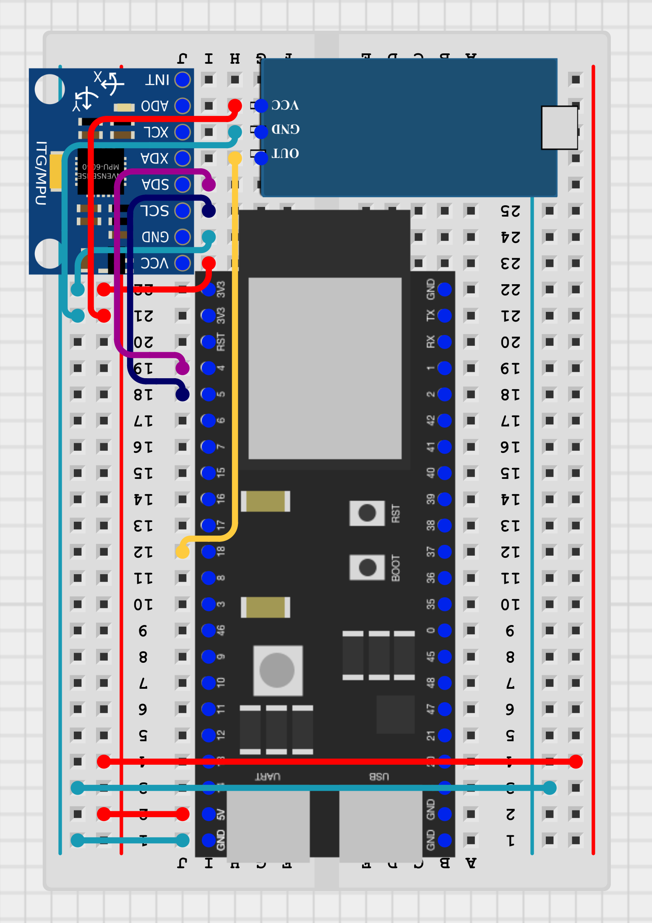
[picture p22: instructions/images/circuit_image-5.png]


Where to connect the OUT pin should match the `sound_pin` variable in `caffeinepod_osc.ino`. By default, the `sound_pin` variable is set to 18, so (unless you changed the value in `caffeinepod_osc.ino`) connect the OUT pin on the sound sensor to pin 18 on the ESP32

**Next, connect the distance sensor**

Connect the VCC pin to the power rail and the GND pin to the power rail. The echo and trig pins should connect to the pins on the ESP32 indicated by the `echo_pin` and `trig_pin` variables, respectively. By default, `echo_pin` is 6 and `trig_pin` is 7.

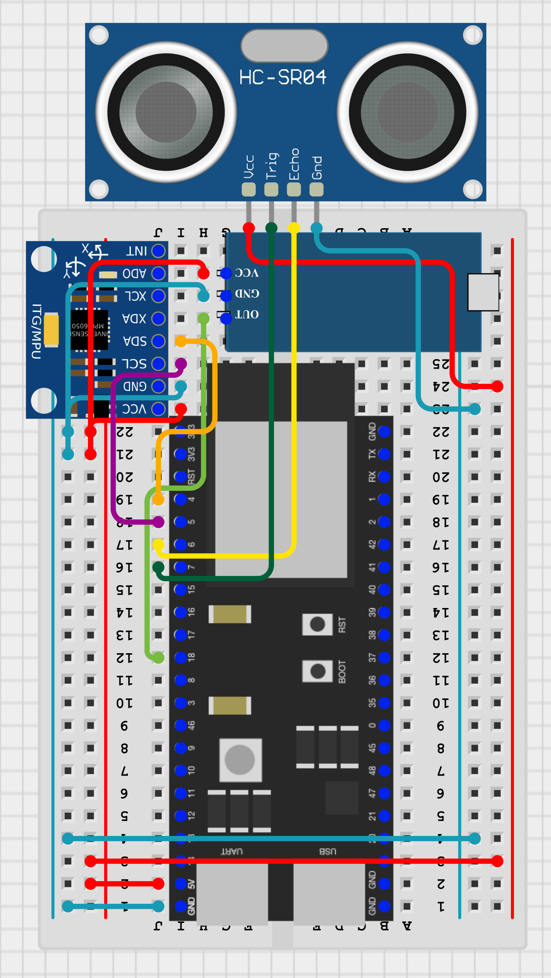
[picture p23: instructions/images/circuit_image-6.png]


### Step 6: The lid

The battery, LiPo rider, and photoresistor go on the lid of the CAFFEINE pod, and they connect to the rest of the components through jumper cables. It may be easiest to first place the components on the lid and then wire everything together.

You should put the photoresistor through the hole in the lid and use some adhesive (like hot glue or tape) to keep it in place. Likewise, use some adhesive to keep the battery and LiPo rider in place. You can really use anything to keep these components in place, as long as they hold on. For example, the image below uses screws to keep the LiPo rider attached to the lid.

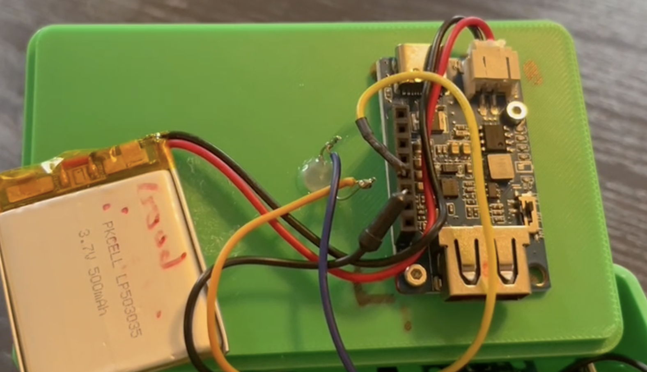
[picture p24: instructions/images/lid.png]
Photo of lid


### Step 7: Wiring the lid components

Once the components are on the lid, you can wire them.

First, connect the photoresistor to the breadboard so the ESP32 can read light measurements. Here is an example schematic of the CAFFEINE pod with the photoresistor wired on:

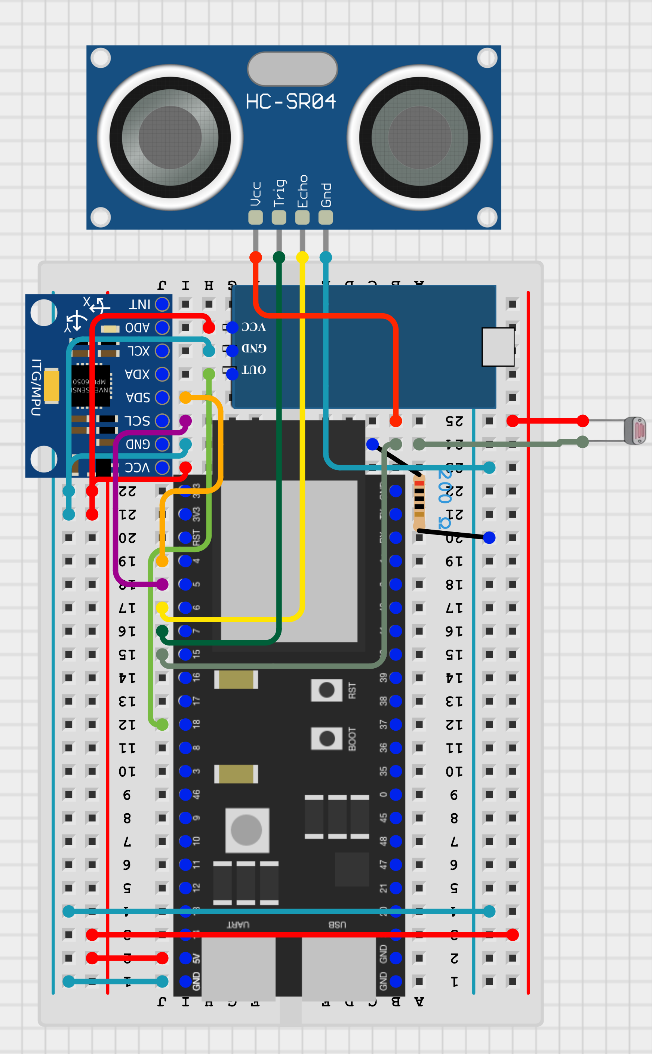
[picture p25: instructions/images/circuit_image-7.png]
CAFFINE pod with LDR


As you can see, one lead of the photoresistor connects to the power rail on the breadboard. The other lead connects to row 24 of the breadboard (or any row with 3 free spaces). Then, a resistor connects from another free space on row 24 to the GND rail on the breadboard. Finally, a jumper wire connects from the final free space on row 24 to the input pin designated by `light_pin` in `caffeinepod_osc.ino` (which is pin 15 by default).

Next, connect the JST connector on the battery to the LiPo rider, as seen in the photo in step 6.

Finally, use jumper wires to connect the GND output of the LiPo rider to the ground (blue) rail on the breadboard. Likewise, connect the 5V output of the LiPo rider to the power (red) rail on the breadboard.

### Step 8: Make noise!

By this point, the CAFFEINE pod hardware is ready to go. From here, fire up the broker and a client file and make some noise!

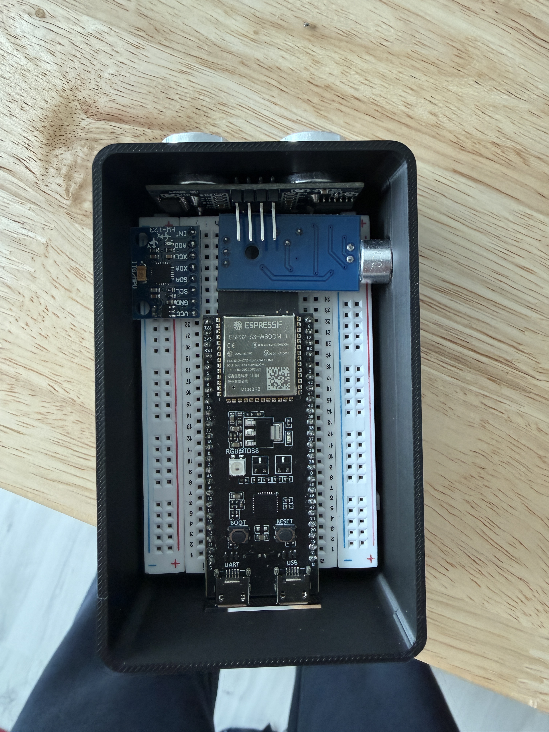
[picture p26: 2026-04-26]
instructions/images/IMG_0954.JPG

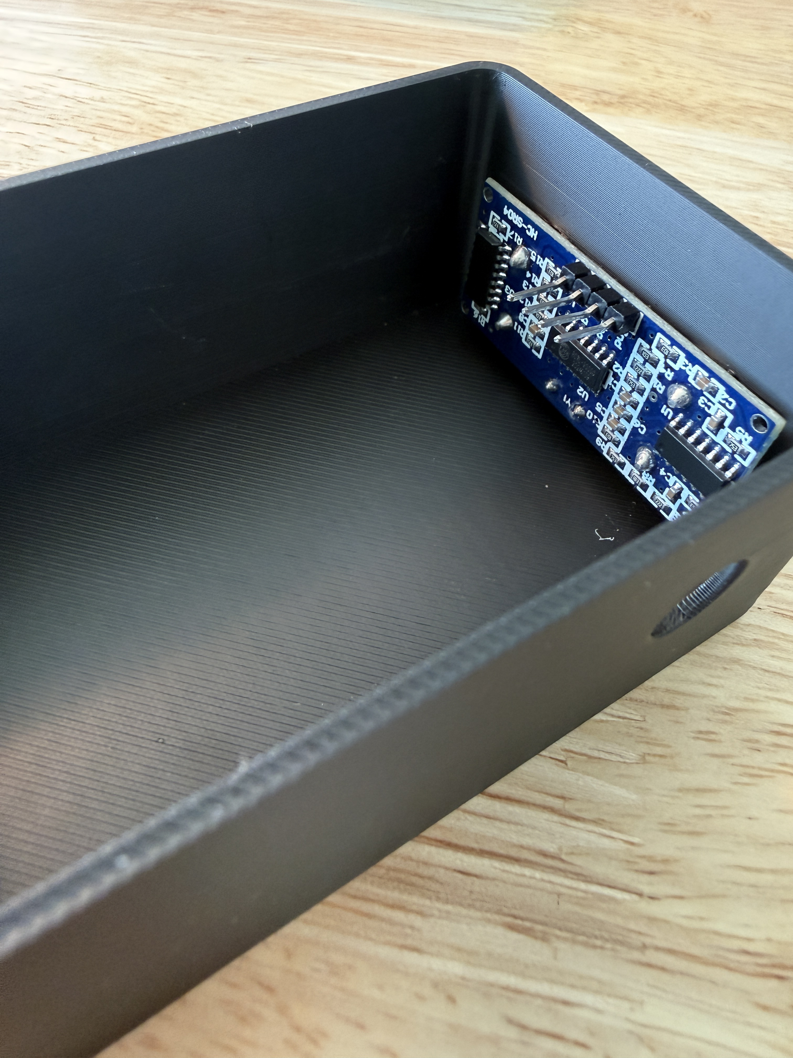
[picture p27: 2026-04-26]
instructions/images/IMG_0951.JPG

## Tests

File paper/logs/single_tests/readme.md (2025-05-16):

This folder contains  files referenced in the CAFFEINE paper. These CSV files contain the results of test 1, Single-Pod Tests. Those tests measured end-to-end latency from pods 1, 2, and 3 from pod to broker to endpoint.

Details: Pod configurations were as follows -

pod1 - all devices listed in paper
pod2 - only mpu6050
pod3 - only light and sound sensors

Details: computers

broker program was running on 2024 Thinkpad P14s Gen 5 with 32 GB RAM

endpoint programs were running on an HP Stream 11-ah011wm with 4 GB RAM

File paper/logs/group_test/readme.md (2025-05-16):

This folder contains test files in CSV format for the Multi-Pod Tests run with varying pod configurations for the CAFFEINE paper.

Private Network (Nighthawk)

Pod1 -> Broker -> endpoint_logger_1 (ThinkPad T440p)
Pod2 -> Broker -> endpoint_logger_2 (Dell Precision 3530)
Pod3 -> Broker -> endpoint_logger_3 (HP Stream)

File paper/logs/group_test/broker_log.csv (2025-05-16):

system_time | pod | remote_timestamp | latency_ms | sequence_number | dropped_in_interval | dropped_total | loss_percent
2025-05-15T11:13:07.545988 | /pod3 | 1747321987.007723 | 538.252 | 0 | 0 | 0 | 0.0
2025-05-15T11:13:07.546777 | /pod3 | 1747321987.017425 | 529.344 | 1 | 0 | 0 | 0.0
2025-05-15T11:13:07.547335 | /pod3 | 1747321987.027419 | 519.908 | 2 | 0 | 0 | 0.0
2025-05-15T11:13:07.547991 | /pod3 | 1747321987.397427 | 150.557 | 39 | 36 | 36 | 90.0
2025-05-15T11:13:07.548409 | /pod3 | 1747321987.407426 | 140.975 | 40 | 0 | 36 | 87.805
2025-05-15T11:13:07.548791 | /pod3 | 1747321987.417427 | 131.359 | 41 | 0 | 36 | 85.714
2025-05-15T11:13:07.549129 | /pod3 | 1747321987.427426 | 121.699 | 42 | 0 | 36 | 83.721
2025-05-15T11:13:07.549597 | /pod3 | 1747321987.437427 | 112.164 | 43 | 0 | 36 | 81.818
2025-05-15T11:13:07.550183 | /pod3 | 1747321987.447426 | 102.751 | 44 | 0 | 36 | 80.0
2025-05-15T11:13:07.550372 | /pod3 | 1747321987.457427 | 92.942 | 45 | 0 | 36 | 78.261
2025-05-15T11:13:07.550897 | /pod3 | 1747321987.467426 | 83.467 | 46 | 0 | 36 | 76.596
2025-05-15T11:13:07.551458 | /pod3 | 1747321987.477427 | 74.028 | 47 | 0 | 36 | 75.0
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

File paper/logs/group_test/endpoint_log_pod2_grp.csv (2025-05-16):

system_time | remote_timestamp | latency_ms | sequence_number
2025-05-15T11:13:10.074552 | 1747321989.525797 | 548.748 | 0
2025-05-15T11:13:10.076574 | 1747321989.535758 | 540.81 | 1
2025-05-15T11:13:10.077733 | 1747321989.54576 | 531.969 | 2
2025-05-15T11:13:10.078809 | 1747321989.855762 | 223.042 | 33
2025-05-15T11:13:10.079629 | 1747321989.865759 | 213.867 | 34
2025-05-15T11:13:10.080426 | 1747321989.875761 | 204.662 | 35
2025-05-15T11:13:10.081119 | 1747321989.88576 | 195.356 | 36
2025-05-15T11:13:10.082184 | 1747321989.89576 | 186.42 | 37
2025-05-15T11:13:10.084637 | 1747321989.90576 | 178.872 | 38
2025-05-15T11:13:10.086551 | 1747321989.91576 | 170.787 | 39
2025-05-15T11:13:10.086869 | 1747321989.925759 | 161.105 | 40
2025-05-15T11:13:10.087733 | 1747321989.935761 | 151.965 | 41
2025-05-15T11:13:10.089570 | 1747321989.94576 | 143.805 | 42
2025-05-15T11:13:10.089875 | 1747321989.955762 | 134.107 | 43
2025-05-15T11:13:10.091050 | 1747321989.96576 | 125.286 | 44
2025-05-15T11:13:10.092034 | 1747321989.975761 | 116.269 | 45
2025-05-15T11:13:10.093012 | 1747321989.985759 | 107.25 | 46
2025-05-15T11:13:10.093974 | 1747321989.99576 | 98.211 | 47
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

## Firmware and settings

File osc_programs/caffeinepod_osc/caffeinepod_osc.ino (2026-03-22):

/*
 *  Adding all sensors here.
 *  This is work-in-progress proof-of-concept code for a many-to-many via broker network topology. Here we assume:
 *  1. Each pod will use this code (Arduino). You must edit the String podname line to indicate a different pod name fomatted as "/pod1", "/pod2", etc
 *  2. The broker.py code (Python3) is running on a computer whose IP is entered below in the udpAddress line and that must contain the /pod(s) entered here.
 *  3. The client.scd code is running (SuperCollider) correctly (see the setup in the client.scd document) 
 *  
 *  Version 1.4

 *  Wish list:
 *  - Low-pass filter all sensors to remove jitter? Or better in client/broker?
 *  - Optimize sound sensor code
 *  - 
 */
#include <Wire.h>
#include <MPU6050_light.h>
#include <WiFi.h>
#include <WiFiUdp.h>
#include <ArduinoOSCWiFi.h>

// ---- Rounding helper (2 decimals, preserves -1 sentinel) ----
static inline float round2f_keep(float v) {
  if (v == -1.0f) return v;
  float scaled = v * 100.0f;
  scaled += (scaled >= 0.0f) ? 0.5f : -0.5f;  // true rounding
  long i = (long)scaled;
  return (float)i / 100.0f;
}
// ---- end rounding helper ----


// ===== HC-SR04: Non-blocking interrupt-based timing (self-contained) =====
#ifndef HCSR04_ISR_BLOCK
#define HCSR04_ISR_BLOCK

// Tunables
static const uint32_t HCSR04_PING_INTERVAL_MS = 75;     // safe cadence for HC-SR04
static const uint32_t HCSR04_ECHO_TIMEOUT_US  = 30000;  // cap wait (~5 m RTD)

// Private copies of your pins (set at runtime in setupHCSR04)
static int _hcsr04_trig_pin = -1;
static int _hcsr04_echo_pin = -1;

// Shared ISR state
volatile uint32_t _hcsr04_rise_us = 0;
volatile uint32_t _hcsr04_fall_us = 0;
volatile bool     _hcsr04_pulse_done = false;

// Main-loop state
static bool     _hcsr04_ping_inflight = false;
static uint32_t _hcsr04_ping_start_us = 0;
static uint32_t _hcsr04_last_ping_ms  = 0;

// Latest computed distance (cm), -1.0 on timeout/no-echo
static volatile float _hcsr04_last_cm = -1.0f;

// ISR: timestamps rising and falling edges on the echo pin
#if defined(ESP32)
void IRAM_ATTR _hcsr04_echo_isr() {
#else
void _hcsr04_echo_isr() {
#endif
  // NOTE: reading the pin here is unnecessary; we get edge via CHANGE
  uint32_t t = micros();
  if (digitalRead(_hcsr04_echo_pin)) {
    _hcsr04_rise_us = t;
    _hcsr04_pulse_done = false;
  } else {
    _hcsr04_fall_us = t;
    _hcsr04_pulse_done = true;
  }
}

// Trigger a 10 µs pulse on the configured TRIG pin
static inline void _hcsr04_trigger_ping() {
  digitalWrite(_hcsr04_trig_pin, LOW);
  delayMicroseconds(2);
  digitalWrite(_hcsr04_trig_pin, HIGH);
  delayMicroseconds(10);
  digitalWrite(_hcsr04_trig_pin, LOW);
}

// Call this once from your setup(), passing your existing pin variables
static inline void setupHCSR04(int trig, int echo) {
  _hcsr04_trig_pin = trig;
  _hcsr04_echo_pin = echo;

  pinMode(_hcsr04_trig_pin, OUTPUT);
  pinMode(_hcsr04_echo_pin, INPUT);
  digitalWrite(_hcsr04_trig_pin, LOW);

  attachInterrupt(digitalPinToInterrupt(_hcsr04_echo_pin), _hcsr04_echo_isr, CHANGE);
}

// Call this each loop iteration (fast, non-blocking)
static inline void serviceHCSR04() {
  const uint32_t now_ms = millis();
  const uint32_t now_us = micros();

  // Start a new ping if due and none in flight
  if (!_hcsr04_ping_inflight && (now_ms - _hcsr04_last_ping_ms >= HCSR04_PING_INTERVAL_MS)) {
    _hcsr04_pulse_done = false;
    _hcsr04_rise_us = 0;
    _hcsr04_fall_us = 0;

    _hcsr04_trigger_ping();
    _hcsr04_ping_start_us = now_us;
    _hcsr04_last_ping_ms = now_ms;
    _hcsr04_ping_inflight = true;
  }

  if (_hcsr04_ping_inflight) {
    if (_hcsr04_pulse_done) {
      uint32_t rise, fall;
      noInterrupts();
      rise = _hcsr04_rise_us;
      fall = _hcsr04_fall_us;
      interrupts();

      if (fall >= rise) {
        const unsigned long dur = fall - rise; // µs
        _hcsr04_last_cm = (dur == 0) ? -1.0f : (dur / 58.0f);
      } else {
        _hcsr04_last_cm = -1.0f;
      }
      _hcsr04_ping_inflight = false;
    } else if ((uint32_t)(now_us - _hcsr04_ping_start_us) > HCSR04_ECHO_TIMEOUT_US) {
      _hcsr04_last_cm = -1.0f;  // timeout/no-echo
      _hcsr04_ping_inflight = false;
    }
  }
}

// Thread-safe accessor for the latest distance (cm). Returns -1.0 if invalid.
static inline float hcsr04_get_latest_cm() {
  noInterrupts();
  float v = _hcsr04_last_cm;
  interrupts();
  return v;
}

#endif // HCSR04_ISR_BLOCK
// ===== END HC-SR04 interrupt block =====


// -- VARIABLES --
MPU6050 mpu(Wire);
WiFiUDP udp;
float s_range;
const int light_pin = 15;
const int sound_pin = 18;

// -- PIN DECLARATIONS --

// -- HC-SR04 --
const int echo_pin = 6;
const int trig_pin = 7;

// -- MILLIS VARIABLES --
unsigned long prevTime = 0;
unsigned long curTime;
const long del = 10;  // every 10 milliseconds, send values

// -- SETUP -- MUST BE EDITED FOR NETWORK IP AND POD NUMBER

// -- [EDIT 1] Edit the podname variable and be sure that name appears in the broker.py document in the list of pods. If necessary, add it there.
const char* pod_name = "/pod1";


// WiFi network name and password. For a network that does not require a password, leave an empty string.
const char* networkName = "OMINET2G";  // ESP32 Devkits cannot connect to 5G wireless... must use 2 GHz
const char* networkPswd = "YalOmi$123!";


// -- [EDIT 2] IP address to send UDP data to: either use the ip address of the server or a network broadcast address
const char* udpAddress = "192.168.1.2";  // double check the IP address of the machine running the Python broker
const int udpPort = 5001;               // double check the port too :)

// -- END SETUP --

// Boolean to store connection status
boolean connected = false;

void setup() {
   // Initialize HC-SR04 using your already-defined pins
  setupHCSR04(trig_pin, echo_pin);

  // Initialize the Wire object and set the input pins - adjust if changing pinout on the ESP32
  Wire.setPins(4, 5);
  Wire.begin();

  // Initialize the MPU
  mpu_init();

  // Initilize hardware serial:
  Serial.begin(115200);

  //Connect to the WiFi network
  connectToWiFi(networkName, networkPswd);

  // HC-SR04 Setup
  pinMode(trig_pin, OUTPUT);  // sets the digital pin 7 to output mode
  pinMode(echo_pin, INPUT);   // sets digital pin 6 to input mode
}

void mpu_init() {
  byte status = mpu.begin();
  Serial.print(F("MPU6050 status: "));
  Serial.println(status);
  while (status != 0) {}  // stop everything if could not connect to MPU6050

  Serial.println(F("Calculating offsets, do not move MPU6050"));
  delay(1000);
  // mpu.upsideDownMounting = true; // uncomment this line if the MPU6050 is mounted upside-down
  mpu.calcOffsets();  // gyro and accelero
  Serial.println("Done!\n");
}

void loop() {

  curTime = millis();

  if (curTime - prevTime >= del) {
    prevTime = curTime;
    writeUDP(curTime);
  }
}

void connectToWiFi(const char* ssid, const char* pwd) {
  delay(1000);
  Serial.println("Connecting to WiFi network: " + String(ssid));
  // delete old config
  WiFi.disconnect(true);
  //register event handler
  WiFi.onEvent(WiFiEvent);
  //Initiate connection
  WiFi.begin(ssid, pwd);

  Serial.println("Waiting for WIFI connection...");
}

//wifi event handler
void WiFiEvent(WiFiEvent_t event) {
  switch (event) {
    case ARDUINO_EVENT_WIFI_STA_GOT_IP:  // updated to reflect current IDE V2 WiFiEvent events
      //When connected set
      Serial.print("WiFi connected! IP address: ");
      Serial.println(WiFi.localIP());
      //initializes the UDP state
      //This initializes the transfer buffer
      udp.begin(WiFi.localIP(), udpPort);
      connected = true;
      break;
    case ARDUINO_EVENT_WIFI_STA_DISCONNECTED:  // updated to reflect current IDE V2 WiFiEvent events
      Serial.println("no WiFi connection");
      connected = false;
      break;
  }
}

void writeUDP(int time) {

  // -- Photoresistor Sensor Input: PIN 15
  long s_light = 0;
  for (int i = 0; i < 32; i++) {
    s_light += analogRead(light_pin);
  }
  s_light >>= 5;   // divide by 32

  // int s_light = analogRead(light_pin);

  // -- MPU-6050 -- Gyroscope code
  mpu.update();
  float s_x = mpu.getAngleX();
  float s_y = mpu.getAngleY();
  float s_z = mpu.getAngleZ();

// -- BEGIN HC-SR04 -- Rangefinder code (non-blocking via interrupt)
serviceHCSR04();  // advance the ultrasonic state machine; never blocks

// Read the latest value and store it in your existing s_range variable
float _cm = hcsr04_get_latest_cm();  // cm, or -1.0 if timeout/no-echo
s_range = _cm;

// Keep two decimal places (only for valid readings)
// -- END HC-SR04

  // -- Seeed Grove -- Sound Sensor code
  long s_sound = 0;
  for (int i = 0; i < 32; i++) {
    s_sound += analogRead(sound_pin);
  }
  s_sound >>= 5;

  // -- Send data via OSC message
  // ---- Round values just before send ----
float s_x2 = round2f_keep(s_x);
float s_y2 = round2f_keep(s_y);
float s_z2 = round2f_keep(s_z);
float s_r2 = round2f_keep(s_range);
// ---- end rounding ----

OscWiFi.send(udpAddress, udpPort, pod_name, s_x2, s_y2, s_z2, s_sound, s_r2, s_light);

}

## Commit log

2025-05-16 updated files, added test suite, removed files
    [avg_mgs.csv, broker_log.csv, endpoint_log_pod1.csv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]
2025-09-23 Update README.md
    added prototype image
2025-10-16 box4 revision
    [box4.scad, box4.stl]
2025-10-28 changed names of program to reflect caffeine
    [endpoint_log_pod1_grp.csv]
2025-10-29 Updates to both osc programs and paper readme. Added errata and R1/LDR clarification
    [caffeinepod_osc.ino]
2025-10-30 edited broker to sent pretty_data to clients instead of sensor_data
2026-03-22 Fix case sensitivity for .DS_Store in .gitignore
